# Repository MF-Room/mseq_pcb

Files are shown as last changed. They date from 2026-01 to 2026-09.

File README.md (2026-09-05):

# MSeq PCB



KiCad 10 hardware design for [MSeq embedded](https://github.com/MF-Room/mseq_embedded),
the microcontroller implementation of the [MSeq](https://github.com/MF-Room/mseq) MIDI sequencer.

## Main specs
* MCU: STM32F413CHU6 (Arm Cortex-M4F, 100 MHz), 25 MHz HSE and 32.768 kHz LSE crystals
* MIDI: 2 × IN (H11L1M opto-isolated), 1 × OUT and 1 × THRU (74HCT125 buffered), 5-pin DIN sockets
* USB-C: USB-to-UART bridge (CP2102N) with ESD protection, also powers the board
* Storage: 16 Mbit SPI NOR flash (W25Q16JV) and 256 kbit SPI FRAM (MB85RS256B)
* Power: 5 V from USB, AMS1117-3.3 regulator, ON/OFF switch
* Controls: MASTER/SLAVE sync switch, RESET and BOOT buttons
* Headers: 10-pin SWD/JTAG (1.27 mm), 4-pin I2C header for a display
* LEDs: power, MIDI activity, USB TX/RX
* Board: 2 layers, 135.3 × 78.4 mm, 1.6 mm FR-4, all parts on the top side, made for JLCPCB assembly

## Related repositories
* [mseq_pcb_tb](https://github.com/MF-Room/mseq_pcb_tb) — test bench for the MSeq PCB
* [mseq_embedded](https://github.com/MF-Room/mseq_embedded) — microcontroller implementation of MSeq
* [mseq](https://github.com/MF-Room/mseq) — lightweight MIDI sequencer framework written in Rust

## License
Copyright © 2026 MF Room.

This hardware design is licensed under the CERN Open Hardware Licence Version 2 – Strongly Reciprocal
(SPDX-License-Identifier: `CERN-OHL-S-2.0`). See [LICENSE](LICENSE) for the full text.

Source location: https://github.com/MF-Room/mseq_pcb

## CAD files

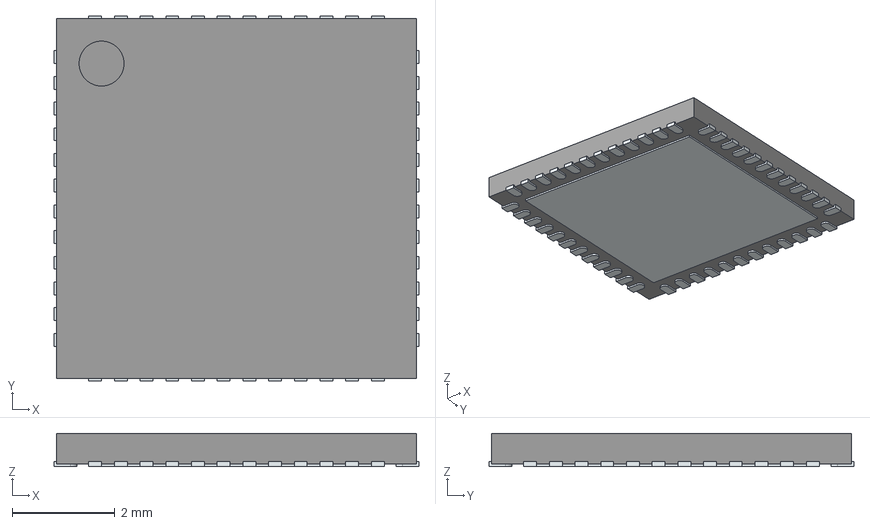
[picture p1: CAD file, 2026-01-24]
fps/stps/STM32F413CHU3TR.stp
7.10 x 7.10 x 0.65 mm
ThermalPin
PinsArrayLR
PinsArrayTB

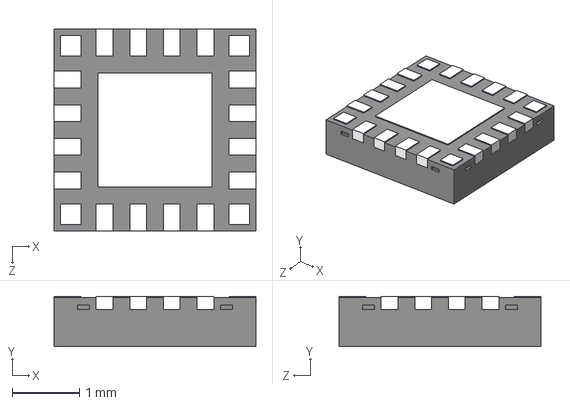
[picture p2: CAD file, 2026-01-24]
fps/stps/CP2102N-A02-GQFN20R.stp
3.00 x 0.75 x 3.00 mm

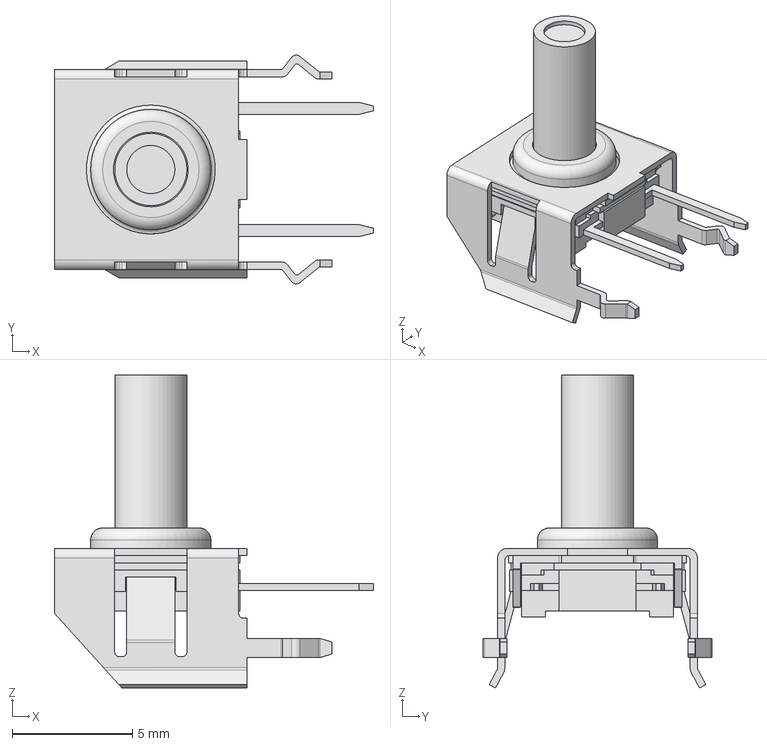
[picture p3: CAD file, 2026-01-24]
fps/stps/TL6110DF160QP.stp
13.3 x 9.50 x 13.0 mm

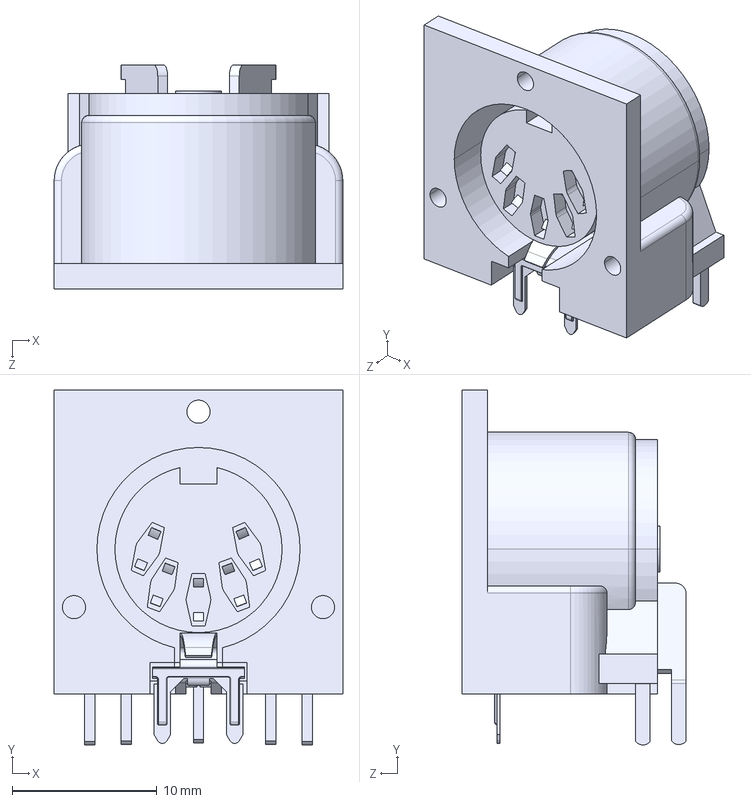
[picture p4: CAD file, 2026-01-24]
fps/stps/57PC5F.step
20.0 x 24.5 x 15.5 mm

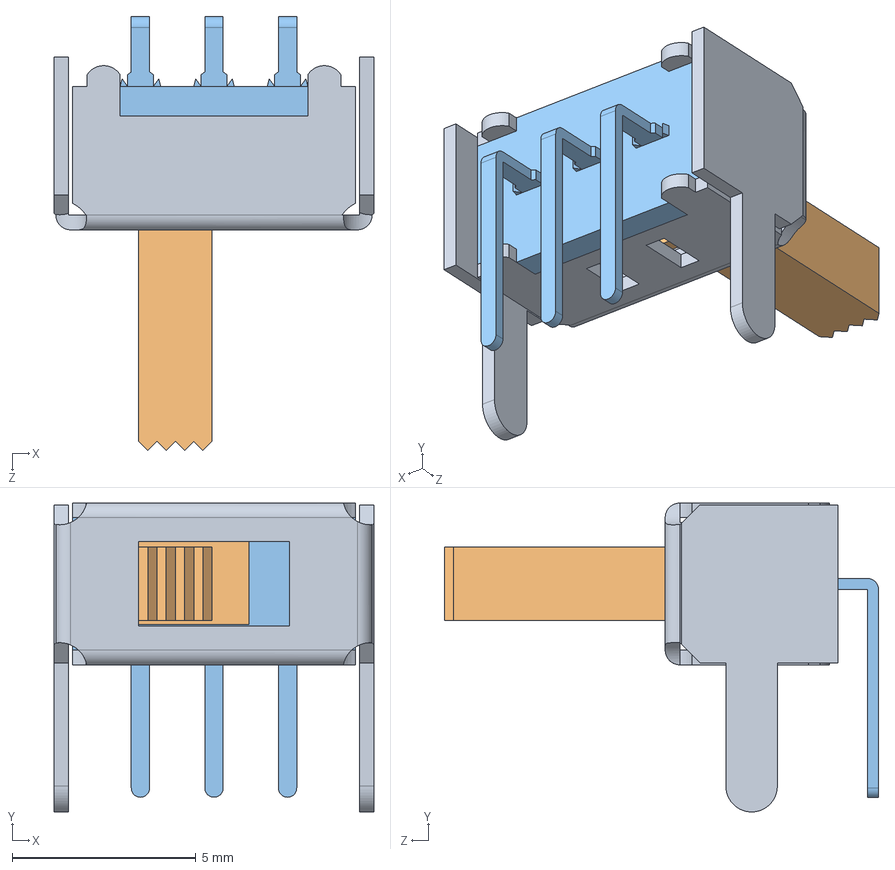
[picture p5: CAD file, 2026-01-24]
fps/stps/SLW-874744-6A-RA-N-D.step
8.70 x 8.40 x 11.8 mm

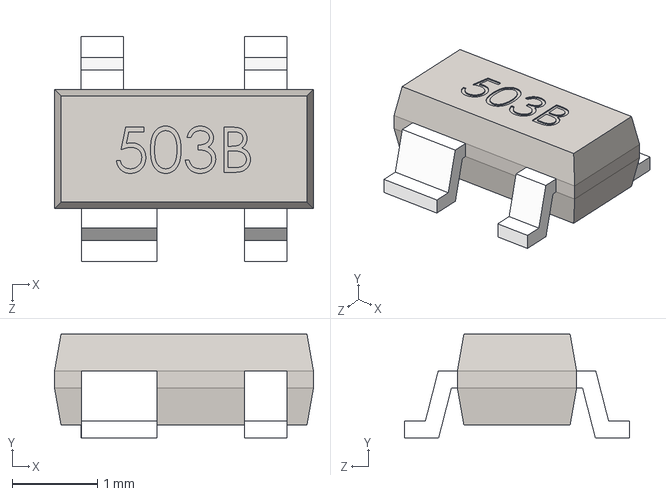
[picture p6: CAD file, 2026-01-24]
fps/stps/SP0503BAHTG.stp
3.04 x 1.22 x 2.64 mm

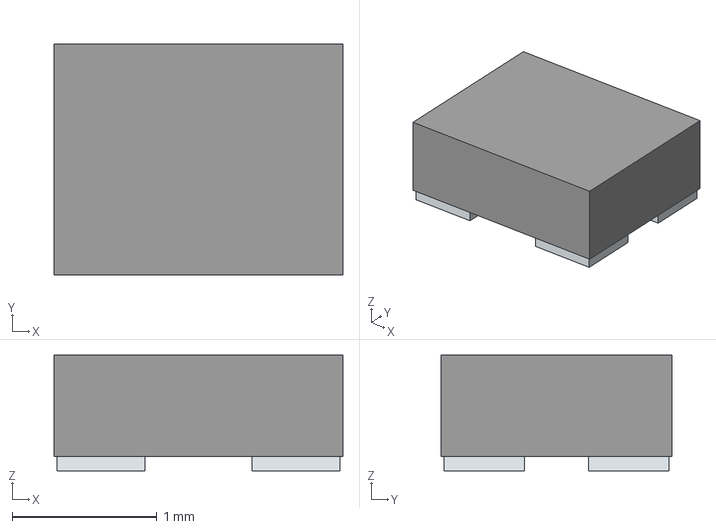
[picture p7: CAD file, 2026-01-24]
fps/stps/XRCGB25M000F1SBJR0.stp
2.00 x 1.60 x 0.8 mm
Pins

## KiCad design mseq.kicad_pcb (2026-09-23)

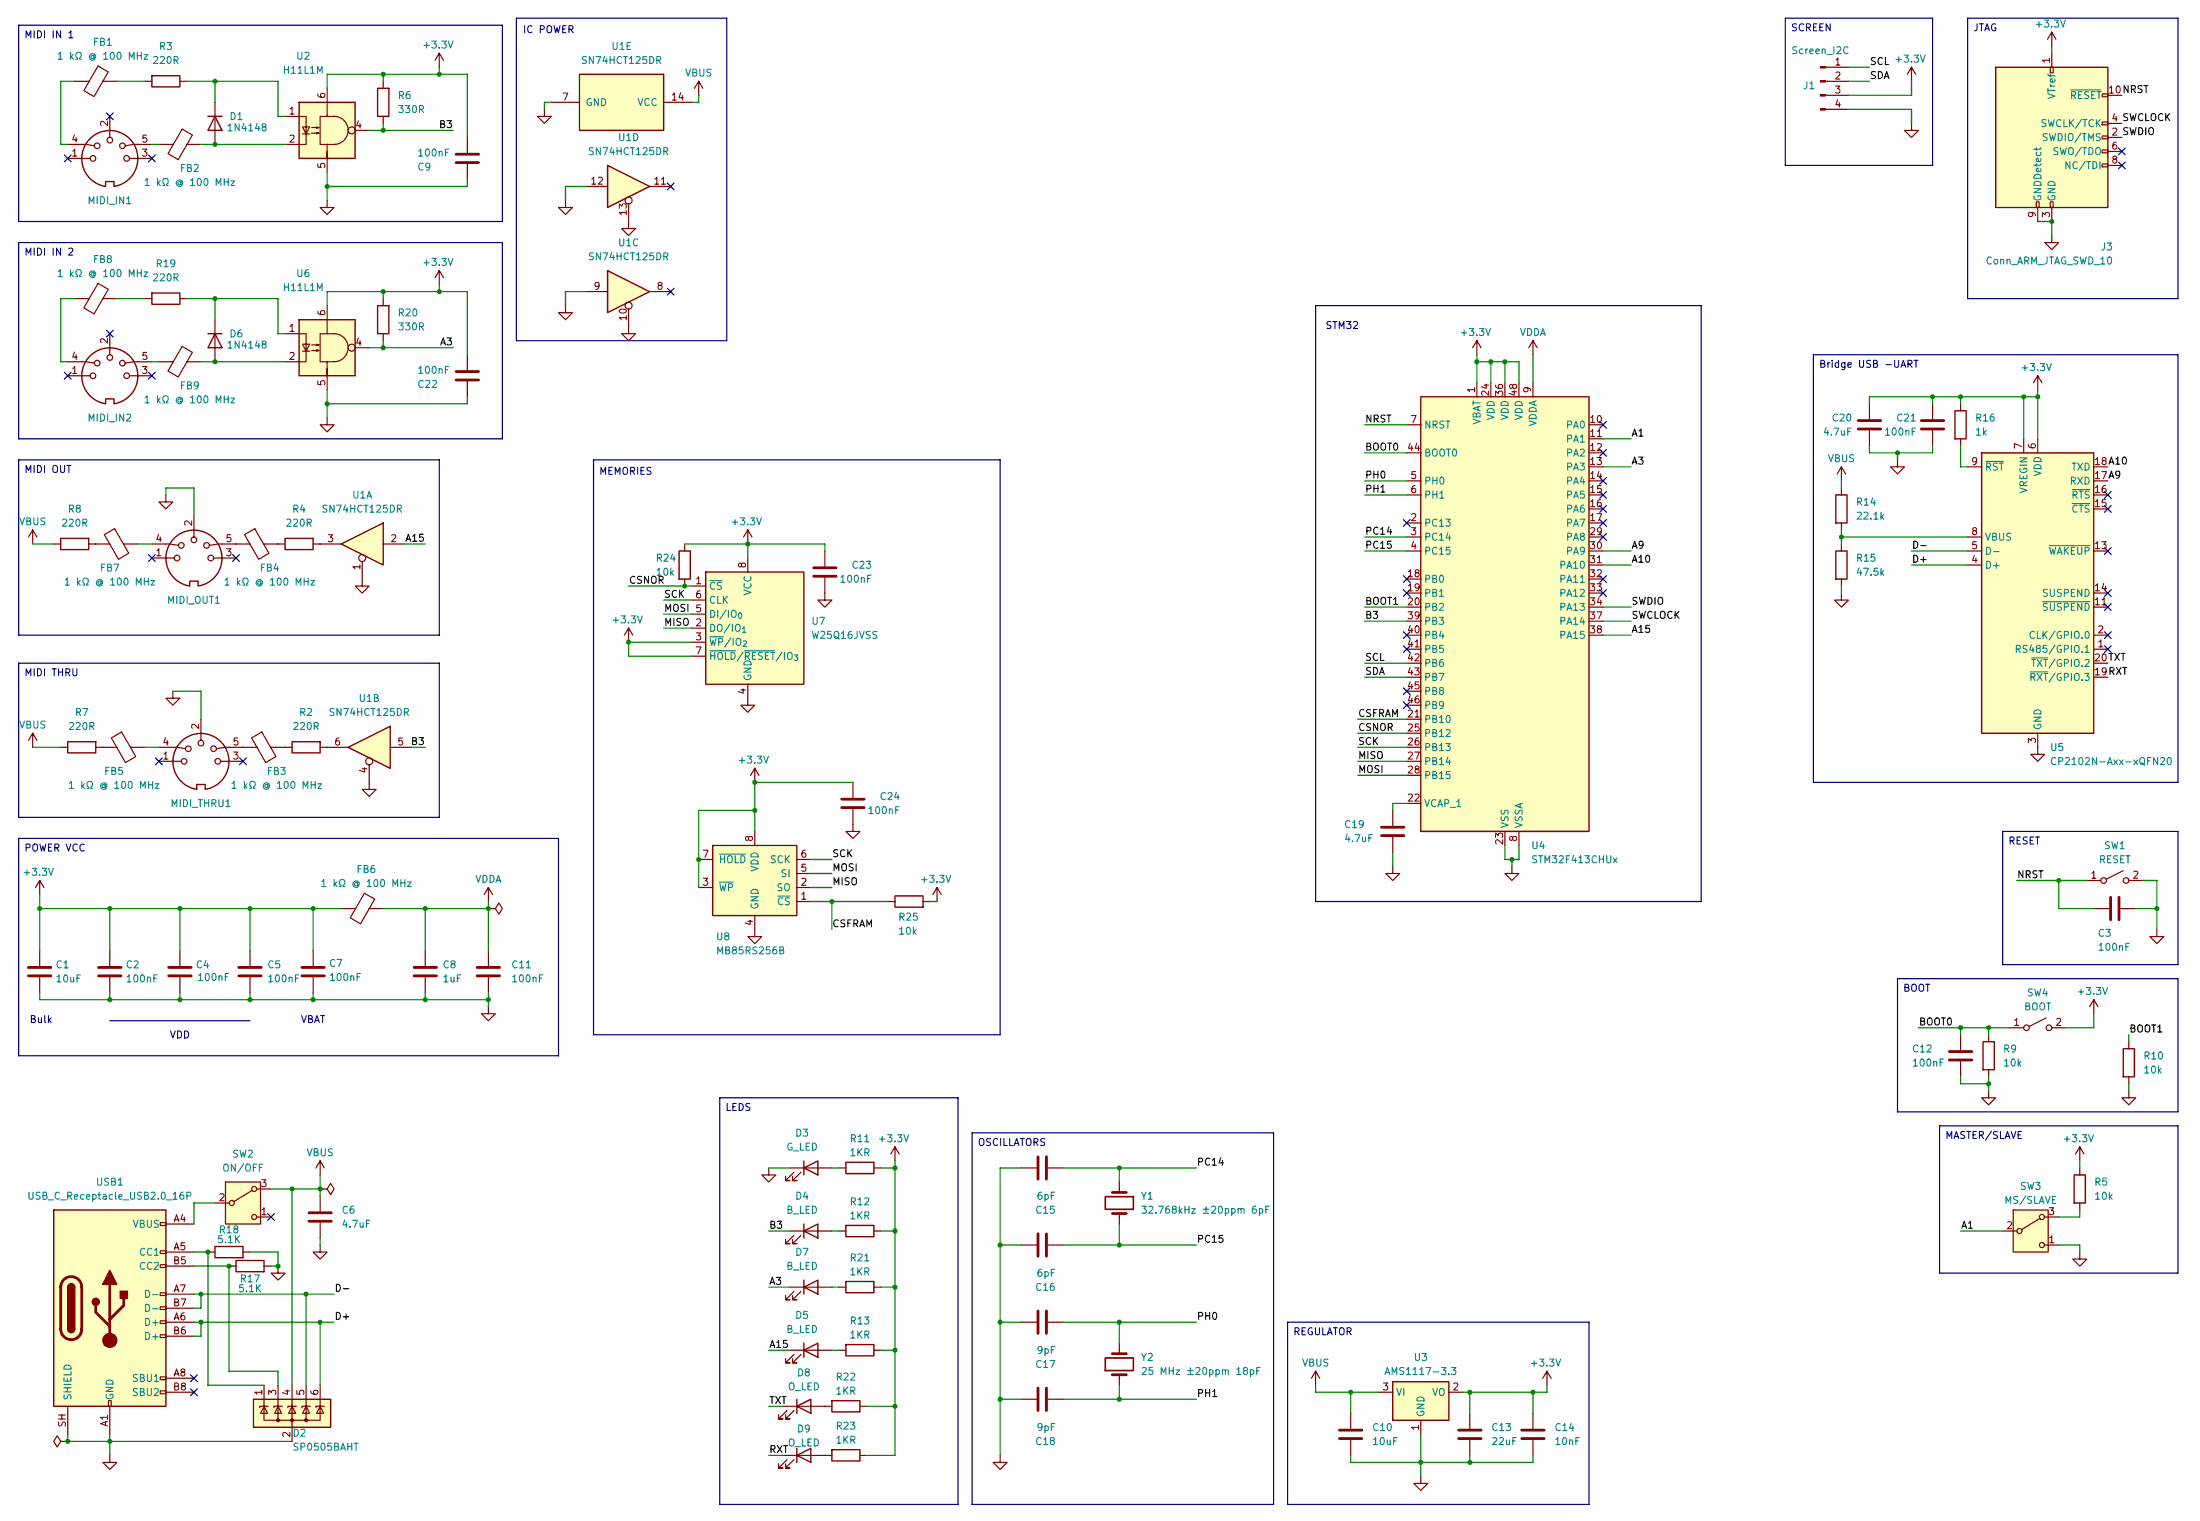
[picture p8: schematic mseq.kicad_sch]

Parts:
C1: 10uF; C_1206_3216Metric; Voltage 50; MPN CL31B106KAHNNNE; LCSC C14860
C2, C3, C4, C5, C7, C9, C11, C12, C21, C22, C23, C24: 100nF; C_0603_1608Metric; Voltage 50; MPN 06035C104JAT2A; LCSC C129176
C6, C19, C20: 4.7uF; C_1206_3216Metric; Voltage 25; MPN CL31B475KAHNNNE; LCSC C1872
C8: 1uF; C_0805_2012Metric; voltage rating 25; MPN CL21F105ZAFNNNE; LCSC C1761
C10: 10uF; C_1206_3216Metric; Voltage 25; MPN CL31B106KAHNNNE; LCSC C14860
C13: 22uF; C_1206_3216Metric; Voltage 25; MPN CL31A226KAHNNNE; LCSC C12891
C14: 10nF; C_0603_1608Metric; Voltage 50; MPN 06035C103JAT2A; LCSC C597189
C15, C16: 6pF; C_0603_1608Metric; MPN 0603CG6R0C500NT; LCSC C37474
C17, C18: 9pF; C_0805_2012Metric; MPN 0805CG9R0C500NT; LCSC C1844
D1, D6: 1N4148; D_SOD-123; MPN 1N4148W-E3-08; LCSC C727110
D2: SP0505BAHT; SOT-23-6; MPN SP0505BAHTG; LCSC C151299
D3: G_LED; LED_0603_1608Metric; MPN E6Q0603VGAC1UDA; LCSC C375576
D4, D5, D7: B_LED; LED_0603_1608Metric; MPN E6Q0603QBAC1UDA; LCSC C375575
D8, D9: O_LED; LED_0603_1608Metric; MPN TJ-S1608SW9T6ALC0A-A5; LCSC C601658
FB1, FB2, FB3, FB4, FB5, FB6, FB7, FB8, FB9: 1 kΩ @ 100 MHz; L_TDK_MLZ1608; MPN MMZ1608R102ATA00; LCSC C89445
J1: Screen_I2C; PinHeader_1x04_P2.54mm_Vertical; MPN 2.54-1*4P; LCSC C2718488
J3: Conn_ARM_JTAG_SWD_10; PinHeader_2x05_P1.27mm_Vertical_SMD; MPN FTSH-105-01-L-DV-K-TR; LCSC C448647
MIDI_IN1, MIDI_IN2: DIN-5_180degree; DIN-504; MPN DIN-504; LCSC C23689428
MIDI_OUT1: DIN-5_180degree; DIN-504; MPN DIN-504; LCSC C23689428
MIDI_THRU1: DIN-5_180degree; DIN-504; MPN DIN-504; LCSC C23689428
R2, R3, R4, R7, R8, R19: 220R; R_0603_1608Metric; MPN 0603WAF2200T5E; LCSC C22962
R5, R9, R10, R24, R25: 10k; R_0603_1608Metric; MPN RCA0310KJLF; LCSC C22369937
R6, R20: 330R; R_0603_1608Metric; MPN CRCW0603330RJNEA; LCSC C844777
R11, R12, R13, R21, R22, R23: 1KR; R_0805_2012Metric; MPN 0805W8F1001T5E; LCSC C17513
R14: 22.1k; R_0805_2012Metric; MPN RT0805BRD0722K1L; LCSC C865310
R15: 47.5k; R_0603_1608Metric; MPN 0603WAF4752T5E; LCSC C23061
R16: 1k; R_0603_1608Metric; MPN 0603WAF1001T5E; LCSC C21190
R17, R18: 5.1K; R_0603_1608Metric; MPN 0603WAF5101T5E; LCSC C23186
SW1: RESET; SW2_1825027-A_TEC; MPN 1825027-5; LCSC C86476
SW2: ON/OFF; SW_Slide_SPDT_Angled_CK_OS102011MA1Q; MPN OS102011MA1QS1; LCSC C221530
SW3: MS/SLAVE; SW_Slide_SPDT_Angled_CK_OS102011MA1Q; MPN OS102011MA1QS1; LCSC C221530
SW4: BOOT; SW2_1825027-A_TEC; MPN 1825027-5; LCSC C86476
U1: SN74HCT125DR; SOIC-14_3.9x8.7mm_P1.27mm; MPN SN74HCT125DR; LCSC C352957
U2, U6: H11L1M; SMDIP-6_W9.53mm; MPN H11L1SM; LCSC C899473
U3: AMS1117-3.3; SOT-223-3_TabPin2; MPN AMS1117-3.3; LCSC C6186
U4: STM32F413CHUx; QFN-48-1EP_7x7mm_P0.5mm_EP5.6x5.6mm; MPN STM32F413CHU6; LCSC C1337761
U5: CP2102N-Axx-xQFN20; SiliconLabs_QFN-20-1EP_3x3mm_P0.5mm_EP1.8x1.8mm; MPN CP2102N-A02-GQFN20R; LCSC C969913
U7: W25Q16JVSS; SOIC-8_5.3x5.3mm_P1.27mm; MPN W25Q16JVSSIQ; LCSC C131025
U8: MB85RS256B; SOIC-8_3.9x4.9mm_P1.27mm; MPN MB85RS256BPNF-G-JNERE1; LCSC C8742
USB1: USB_C_Receptacle_USB2.0_16P; USB_C_Receptacle_HRO_TYPE-C-31-M-12; MPN TYPE-C-31-M-12; LCSC C165948
Y1: 32.768kHz ±20ppm 6pF; Crystal_SMD_MicroCrystal_CC7V-T1A-2Pin_3.2x1.5mm; MPN CM7V-T1A-32.768kHz-6pF-20PPM-TA-QC; LCSC C5366534
Y2: 25 MHz ±20ppm 18pF; Crystal_SMD_5032-2Pin_5.0x3.2mm; MPN ABM3-25.000MHZ-D2Y-T; LCSC C148312

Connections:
+3.3V: C1.1, C2.1, C4.1, C5.1, C7.1, C9.1, C13.1, C14.1, C20.1, C21.2, C22.1, C23.2, C24.2, FB6.2, J1.3, J3.1 (VTref), R5.1, R6.2, R11.1, R12.1, R13.1, R16.1, R20.2, R21.1, R22.1, R23.1, R24.1, R25.2, SW4.2 (B), U2.6, U3.2 (VO), U4.1 (VBAT), U4.24 (VDD), U4.36 (VDD), U4.48 (VDD), U5.6 (VDD), U5.7 (VREGIN), U6.6, U7.3 (~WP/IO_{2}), U7.7 (~HOLD/~RESET/IO_{3}), U7.8 (VCC), U8.3 (~WP), U8.7 (~HOLD), U8.8 (VDD)
/A1: SW3.2 (B), U4.11 (PA1)
/A3: D7.1 (K), R20.1, U4.13 (PA3), U6.4
/A9: U4.30 (PA9), U5.17 (RXD)
/A10: U4.31 (PA10), U5.18 (TXD)
/A15: D5.1 (K), U1.2, U4.38 (PA15)
/B3: D4.1 (K), R6.1, U1.5, U2.4, U4.39 (PB3)
/BOOT0: C12.1, R9.1, SW4.1 (A), U4.44 (BOOT0)
/BOOT1: R10.1, U4.20 (PB2)
/CSFRAM: R25.1, U4.21 (PB10), U8.1 (~CS)
/CSNOR: R24.2, U4.25 (PB12), U7.1 (~CS)
/D+: D2.6 (K), U5.4 (D+), USB1.A6 (D+), USB1.B6 (D+)
/D-: D2.5 (K), U5.5 (D-), USB1.A7 (D-), USB1.B7 (D-)
/MISO: U4.27 (PB14), U7.2 (DO/IO_{1}), U8.2 (SO)
/MOSI: U4.28 (PB15), U7.5 (DI/IO_{0}), U8.5 (SI)
/NRST: C3.1, J3.10 (~RESET), SW1.1 (A), U4.7 (NRST)
/PC14: C15.1, U4.3 (PC14), Y1.1
/PC15: C16.1, U4.4 (PC15), Y1.2
/PH0: C17.1, U4.5 (PH0), Y2.2
/PH1: C18.1, U4.6 (PH1), Y2.1
/RXT: D9.1 (K), U5.19 (~RXT/GPIO.3)
/SCK: U4.26 (PB13), U7.6 (CLK), U8.6 (SCK)
/SCL: J1.1, U4.42 (PB6)
/SDA: J1.2, U4.43 (PB7)
/SWCLOCK: J3.4 (SWCLK/TCK), U4.37 (PA14)
/SWDIO: J3.2 (SWDIO/TMS), U4.34 (PA13)
/TXT: D8.1 (K), U5.20 (~TXT/GPIO.2)
GND: C1.2, C2.2, C3.2, C4.2, C5.2, C6.2, C7.2, C8.2, C9.2, C10.2, C11.2, C12.2, C13.2, C14.2, C15.2, C16.2, C17.2, C18.2, C19.2, C20.2, C21.1, C22.2, C23.1, C24.1, D2.2 (A), D3.1 (K), J1.4, J3.3 (GND), J3.5 (GND), J3.9 (GNDDetect), MIDI_OUT1.2, MIDI_THRU1.2, R9.2, R10.2, R15.2, R17.2, R18.2, SW1.2 (B), SW3.1 (C), U1.1, U1.4, U1.7 (GND), U1.9, U1.10, U1.12, U1.13, U2.5, U3.1 (GND), U4.8 (VSSA), U4.23 (VSS), U4.35 (VSS), U4.47 (VSS), U4.49 (VSS), U5.3 (GND), U5.12 (GND), U5.21 (GND), U6.5, U7.4 (GND), U8.4 (GND), USB1.A1 (GND), USB1.A12 (GND), USB1.B1 (GND), USB1.B12 (GND), USB1.SH (SHIELD)
unnamed: D1.2 (A), FB2.1, U2.2
unnamed: D1.1 (K), R3.1, U2.1
unnamed: D3.2 (A), R11.2
unnamed: D4.2 (A), R12.2
unnamed: D5.2 (A), R13.2
unnamed: D6.2 (A), FB9.1, U6.2
unnamed: D6.1 (K), R19.1, U6.1
unnamed: D7.2 (A), R21.2
unnamed: D8.2 (A), R22.2
unnamed: D9.2 (A), R23.2
unnamed: FB1.1, R3.2
unnamed: FB1.2, MIDI_IN1.4
unnamed: FB2.2, MIDI_IN1.5
unnamed: FB3.1, MIDI_THRU1.5
unnamed: FB3.2, R2.1
unnamed: FB4.1, MIDI_OUT1.5
unnamed: FB4.2, R4.1
unnamed: FB5.1, R7.2
unnamed: FB5.2, MIDI_THRU1.4
unnamed: FB7.1, R8.2
unnamed: FB7.2, MIDI_OUT1.4
unnamed: FB8.1, R19.2
unnamed: FB8.2, MIDI_IN2.4
unnamed: FB9.2, MIDI_IN2.5
unnamed: R2.2, U1.6
unnamed: R4.2, U1.3
unnamed: SW2.2 (B), USB1.A4 (VBUS), USB1.A9 (VBUS), USB1.B4 (VBUS), USB1.B9 (VBUS)
unnamed: R5.2, SW3.3 (A)
unnamed: C19.1, U4.22 (VCAP_1)
unnamed: R14.2, R15.1, U5.8 (VBUS)
unnamed: R16.2, U5.9 (~RST)
unnamed: D2.1 (K), R18.1, USB1.A5 (CC1)
unnamed: D2.3 (K), R17.1, USB1.B5 (CC2)
VBUS: C6.1, C10.1, D2.4 (K), R7.1, R8.1, R14.1, SW2.3 (A), U1.14 (VCC), U3.3 (VI)
VDDA: C8.1, C11.1, FB6.1, U4.9 (VDDA)

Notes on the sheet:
VDD
MEMORIES
VBAT
Bulk
STM32
IC POWER
SCREEN
MIDI IN 2
MIDI IN 1
MASTER/SLAVE
LEDS
MIDI OUT
REGULATOR
Bridge USB -UART
MIDI THRU
BOOT
POWER VCC
OSCILLATORS
JTAG
RESET

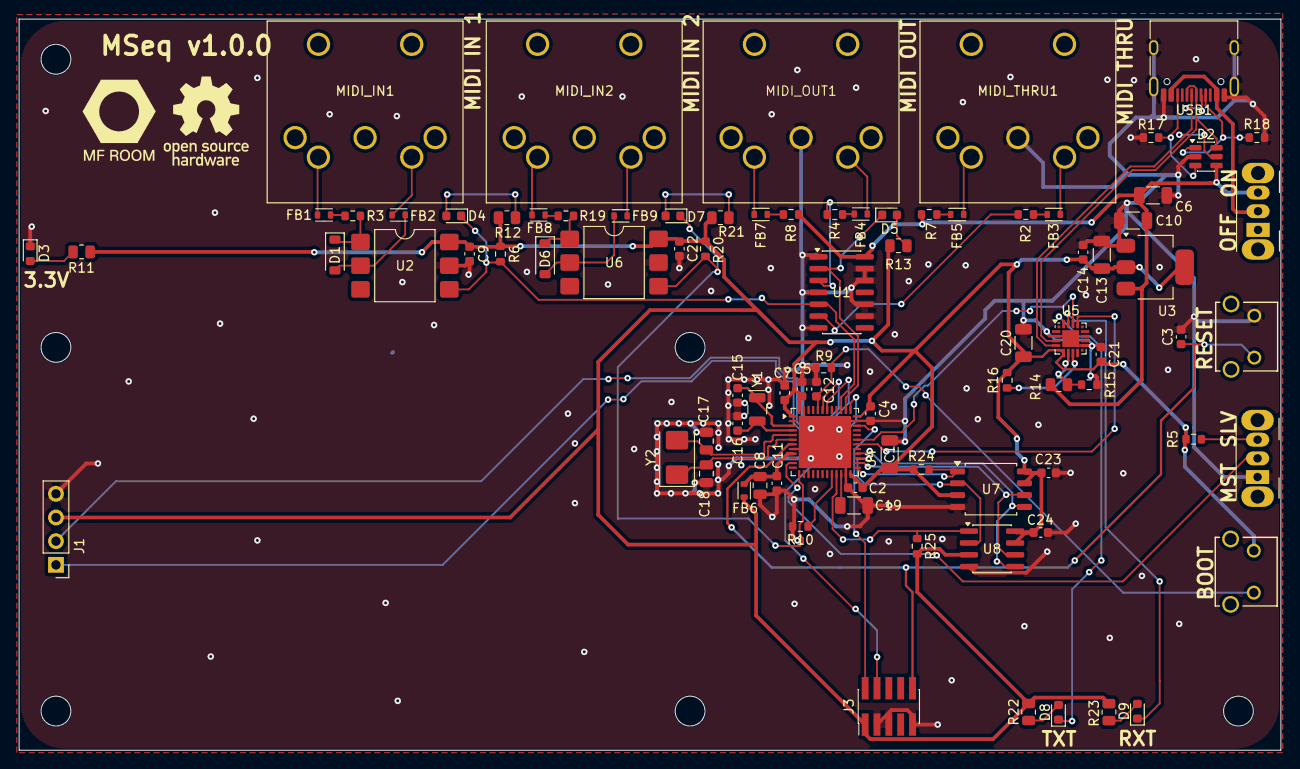
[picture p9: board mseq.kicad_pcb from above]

Board: 2 copper layers, 135.3 x 78.4 mm, 87 parts (0 on the bottom side), 63 nets.

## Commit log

2025-10-19 advance schematic
    [mseq.kicad_sch]
2025-10-29 Power updated
    [mseq.kicad_sch]
2025-11-09 schematic ready for review
    [mseq.kicad_sch]
2025-11-09 work on footprints
    [mseq.kicad_sch]
2025-11-11 Bug fixed
    [mseq.kicad_sch]
2025-11-12 sch done
    [mseq.kicad_sch]
2025-11-20 Updated with new mcu
    [mseq.kicad_sch]
2025-11-22 MPN added
    [mseq.kicad_sch]
2025-11-30 MPN capacitor almost done
    [mseq.kicad_sch]
2025-11-30 Bypass capacitor in VCC don
    [mseq.kicad_sch]
2025-12-02 MPN almost done
    [mseq.kicad_sch]
2025-12-03 MPN for bypass capacitors done
    [mseq.kicad_sch]
2025-12-10 Resistor for MIDI done
    [mseq.kicad_sch]
2025-12-24 MPN for resistors and diodes added
    [mseq.kicad_sch]
2025-12-31 MPN for LED resistor done
    [mseq.kicad_sch]
2026-01-02 Schematic finished. MPN OK. FPs OK.
    [mseq.kicad_sch]
2026-01-24 Placement done.
    [57PC5F.step, CP2102N-A02-GQFN20R.stp, SLW-874744-6A-RA-N-D.step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]
2026-02-28 90% Routing
    [mseq.kicad_pcb]
2026-02-28 finish routing
    [mseq.kicad_pcb]
2026-03-06 Last DRC Check
    [mseq.kicad_pcb]
2026-03-08 v0.1.0 done
    [mseq.kicad_pcb]
2026-03-18 LCSC added and bom script added
    [mseq.kicad_sch]
2026-03-18 Missing LCSC added
    [mseq.kicad_sch]
2026-03-26 LCSC Part Change, need MCP/MPN
    [mseq.kicad_pcb, mseq.kicad_sch]
2026-03-26 Wip MPN
    [mseq.kicad_sch]
2026-03-26 MPN update wip
    [mseq.kicad_sch]
2026-03-26 Almost done
    [mseq.kicad_pcb, mseq.kicad_sch]
2026-05-01 USB connector changed
    [mseq.kicad_pcb, mseq.kicad_sch]
2026-05-01 WIP, need to make the board bigger
    [mseq.kicad_pcb, mseq.kicad_sch]
2026-05-31 Moved to new version of kicad
    [mseq.kicad_sch]
2026-05-31 LED reversed and MIDI out reversed
    [mseq.kicad_sch]
2026-06-27 USB bug fixed and new JTAG connector
    [mseq.kicad_pcb, mseq.kicad_sch]
2026-06-28 Second midi in added
    [mseq.kicad_sch]
2026-07-05 LED for TXT and RXT added
    [mseq.kicad_sch]
2026-07-05 NOR Flash added wip
    [mseq.kicad_sch]
2026-09-01 SPI memories wired, AMS1117 regulator, schematic fixes
    Add the NOR flash and FRAM to a shared SPI2 bus and clean up the
    issues a full schematic review turned up.
    Memories (U7 W25Q16JV, U8 MB85RS256B) share SCK/MOSI/MISO on
    PB13/PB15/PB14 with separate chip selects on PB12 (NOR) and PB10
    (FRAM), each with a 10k pull-up so both stay deselected through
    reset. /WP and /HOLD tied high on both parts. QUADSPI is not
    bonded out on the 48-pin STM32F413CHU6, so this is single SPI;
    the FRAM sets the bus ceiling at 25 MHz for READ.
    Regulator U3 moved from MCP1703A (SOT-23A) to AMS1117-3.3
    (SOT-223). The SOT-23A's 336 C/W thermal resistance left almost
    no margin at the ~166 mA peak load; SOT-223 remove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
    [mseq.kicad_pcb, mseq.kicad_sch]
2026-09-01 PCB updated, wip
    [mseq.kicad_pcb]
2026-09-03 PCB placement & routing WIP
    [mseq.kicad_pcb]
2026-09-05 PCB placement & routing WIP, board logos, DRC exclusions
    Add res/ with the MF Room square logo (dark background removed) and the
    OSHW logo, both transparent SVGs ready for Import Graphics onto silkscreen.
    Exclude the two text_thickness DRC warnings on the OFF and SLV silkscreen
    labels. Not genuinely thin strokes: KiCad's FreeType conversion emits a
    self-intersecting outline for Geist's F and L, so the DRC deflate test
    collapses a degenerate sliver. Reproducible with those glyphs alone at any
    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
    [mseq.kicad_pcb, mseq.kicad_sch]
2026-09-05 Vias added
    [mseq.kicad_pcb]
2026-09-05 Fix DIN-504 footprint pin rows, restore MIDI references, clean fp-lib-table
    - DIN-504: pins 4/5 moved from 2.49 mm to 2.1 mm behind pins 1/2/3 (LCSC
    datasheet for C23689428); updated in the library and on the board
    - DIN footprints use their schematic references (MIDI_IN1 ...) again; the
    front-panel labels are now free silkscreen text, so BOM/CPL designators
    are clean and Update-PCB-from-Schematic no longer renames them
    - TXT/RXT labels: trailing newline removed
    - fp-lib-table: dropped a dangling "fps" entry and a duplicated mseq_lib line
    Claude-Session: https://claude.ai/code/session_014D6qtQcTakGg9PCa4hkr3z
    [mseq.kicad_pcb]
2026-09-05 Add GitHub Actions ERC/DRC check and README badge
    Runs kicad-cli sch erc and pcb drc (with schematic parity and zone refill)
    in the official kicad/kicad:10.0 container on pushes and pull requests
    touching the design. Non-excluded errors fail the job; warnings are shown
    as annotations and in the job summary; JSON reports are uploaded as an
    artifact. Installs the Geist silkscreen font (pinned, checksummed) so silk
    geometry matches local DRC, and recreates KiCad's global library tables
    in the CI home directory.
    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
2026-09-05 Repo cleanup: README rewrite, CERN-OHL-S-2.0 licence, drop utils/
    - README: board description, main specs, links to mseq_pcb_tb, mseq_embedded
    and mseq; old JLCPCB help links removed
    - LICENSE: CERN Open Hardware Licence v2 - Strongly Reciprocal (official text)
    - utils/bom2grouped_csv_jlcpcb.xsl removed (legacy XSLT BOM flow, superseded
    by Fabrication Toolkit)
    - .gitignore: ignore Fabrication Toolkit output (production/) and its
    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
2026-09-05 Board setup: solder mask to copper clearance 0 -> 0.005 mm
    Claude-Session: https://claude.ai/code/session_01MC32manLVEncqMMDzCiPki
2026-09-23 chaged the pin name
    [mseq.kicad_pcb, mseq.kicad_sch]
